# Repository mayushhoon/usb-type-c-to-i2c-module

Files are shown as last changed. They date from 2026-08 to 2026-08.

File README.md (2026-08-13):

# USB Type-C to I2C Bridge Module using FT201X IC

## Overview
A highly compact, production-ready USB Type-C to I2C hardware bridge. This module is designed to interface high-speed USB data from a host PC directly with external I2C peripherals, displays, and sensors. 

Engineered with a strict focus on Design for Manufacturability (DFM) and Design for Assembly (DFA), the board packs power regulation, signal filtering, and data conversion into a 31x17mm footprint using high-density 0603 surface-mount components.

| Front Side | Back Side |
| :---: | :---: |
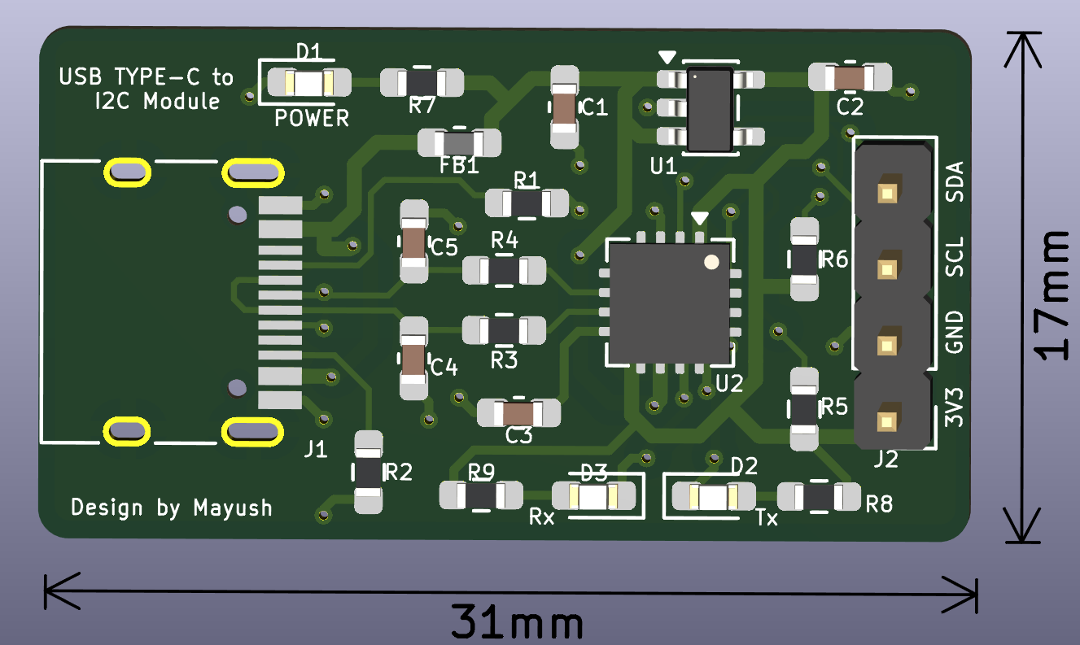
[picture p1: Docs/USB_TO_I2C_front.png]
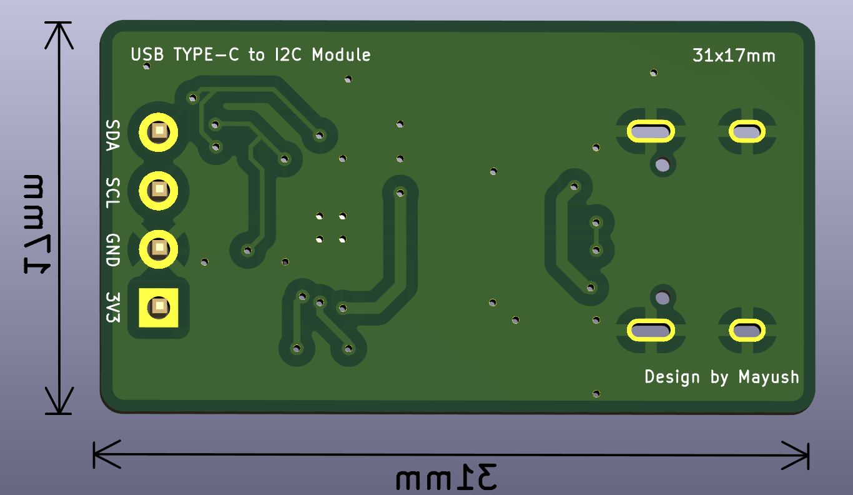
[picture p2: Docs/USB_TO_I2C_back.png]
|  |  |

## Hardware Architecture
* **Core Bridge IC:** FTDI FT201X (Full-Speed USB to I2C Bridge).
* **Power Regulation:** Integrated 3.3V Low Dropout (LDO) regulator to provide clean, low-noise power to both the internal logic and external I2C header.
* **EMI Suppression:** Custom RC low-pass filter network (27Ω / 47pF) on the USB D+ and D- data lines for impedance matching and high-frequency noise mitigation.
* **Bus Stability:** Dedicated 2.2kΩ hardware pull-up resistors on the SDA and SCL lines to guarantee sharp signal edge-rates at Fast Mode (400 kHz) clock speeds.
* **Host Isolation:** Ferrite bead input filtering on the 5V VBUS to block high-frequency switching noise from the host PC.

## Diagnostic Interface
The module features a custom diagnostic LED array utilizing the configurable CBUS pins of the FT201X to provide immediate visual feedback of bus states:
* 🔴 **RED:** Power indicator (Tapped downstream of the input filter).
* 🔵 **BLUE:** RX Data Activity.
* 🟢 **GREEN:** TX Data Activity.

## Board Specifications
| Feature | Specification |
| :--- | :--- |
| **Dimensions** | 31mm x 17mm |
| **Layers** | 2-Layer FR4 (Solid bottom ground plane) |
| **Component Size** | 0603 Imperial (Passives & LEDs) |
| **Trace Width** | 0.254mm (10 mil) standard |
| **Input Interface** | USB Type-C (Receptacle) |
| **Output Interface** | 4-Pin 2.54mm Header (3V3, GND, SCL, SDA) |

## Repository Structure
* `/Hardware` - Source KiCad 7/8 project files (Schematic and PCB layout).
* `/Fabrication` - Manufacturing package (Gerbers, Excellon Drill files, and CSV BOM).
* `/Docs` - PDF schematics, 3D renders, and component datasheets.

## Assembly Notes
This board was intentionally designed to be hand-solderable despite its small size. All passive components use the `_HandSoldering` 0603 footprint variants to provide extended pad surface area for tweezer and iron assembly. Ensure the FT201X internal CBUS pins are configured via the FT_Prog utility to activate the TX and RX LED indicators after assembly.

## Author
**Designed by MAYUSH RAHANGDALE**

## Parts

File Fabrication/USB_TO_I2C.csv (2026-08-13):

Reference | Qty | Value | DNP | Exclude from BOM | Exclude from Board | Footprint | Datasheet
C1,C2 | 2 | 1u |  |  |  | Capacitor_SMD:C_0603_1608Metric_Pad1.08x0.95mm_HandSolder | ~
C3 | 1 | 100n |  |  |  | Capacitor_SMD:C_0603_1608Metric_Pad1.08x0.95mm_HandSolder | ~
C4,C5 | 2 | 47p |  |  |  | Capacitor_SMD:C_0603_1608Metric_Pad1.08x0.95mm_HandSolder | ~
D1 | 1 | RED |  |  |  | LED_SMD:LED_0603_1608Metric_Pad1.05x0.95mm_HandSolder | ~
D2 | 1 | GREEN |  |  |  | LED_SMD:LED_0603_1608Metric_Pad1.05x0.95mm_HandSolder | ~
D3 | 1 | BLUE |  |  |  | LED_SMD:LED_0603_1608Metric_Pad1.05x0.95mm_HandSolder | ~
FB1 | 1 | FerriteBead |  |  |  | Inductor_SMD:L_0603_1608Metric_Pad1.05x0.95mm_HandSolder | ~
J1 | 1 | USB_C_Receptacle_USB2.0_16P |  |  |  | Connector_USB:USB_C_Receptacle_HRO_TYPE-C-31-M-12 | https://www.usb.org/sites/default/files/documents/usb_type-c.zip
J2 | 1 | Conn_01x04_Pin |  |  |  | Connector_PinHeader_2.54mm:PinHeader_1x04_P2.54mm_Vertical | ~
R1,R2 | 2 | 5.1k |  |  |  | Resistor_SMD:R_0603_1608Metric_Pad0.98x0.95mm_HandSolder | ~
R3,R4 | 2 | 27 |  |  |  | Resistor_SMD:R_0603_1608Metric_Pad0.98x0.95mm_HandSolder | ~
R5,R6 | 2 | 2.2k |  |  |  | Resistor_SMD:R_0603_1608Metric_Pad0.98x0.95mm_HandSolder | ~
R7 | 1 | 1k |  |  |  | Resistor_SMD:R_0603_1608Metric_Pad0.98x0.95mm_HandSolder | ~
R8,R9 | 2 | 330 |  |  |  | Resistor_SMD:R_0603_1608Metric_Pad0.98x0.95mm_HandSolder | ~
U1 | 1 | TLV70233_SOT23-5 |  |  |  | Package_TO_SOT_SMD:SOT-23-5 | http://www.ti.com/lit/ds/symlink/tlv702.pdf
U2 | 1 | FT201XQ |  |  |  | Package_DFN_QFN:QFN-16-1EP_4x4mm_P0.65mm_EP2.1x2.1mm | https://www.ftdichip.com/Support/Documents/DataSheets/ICs/DS_FT201X.pdf

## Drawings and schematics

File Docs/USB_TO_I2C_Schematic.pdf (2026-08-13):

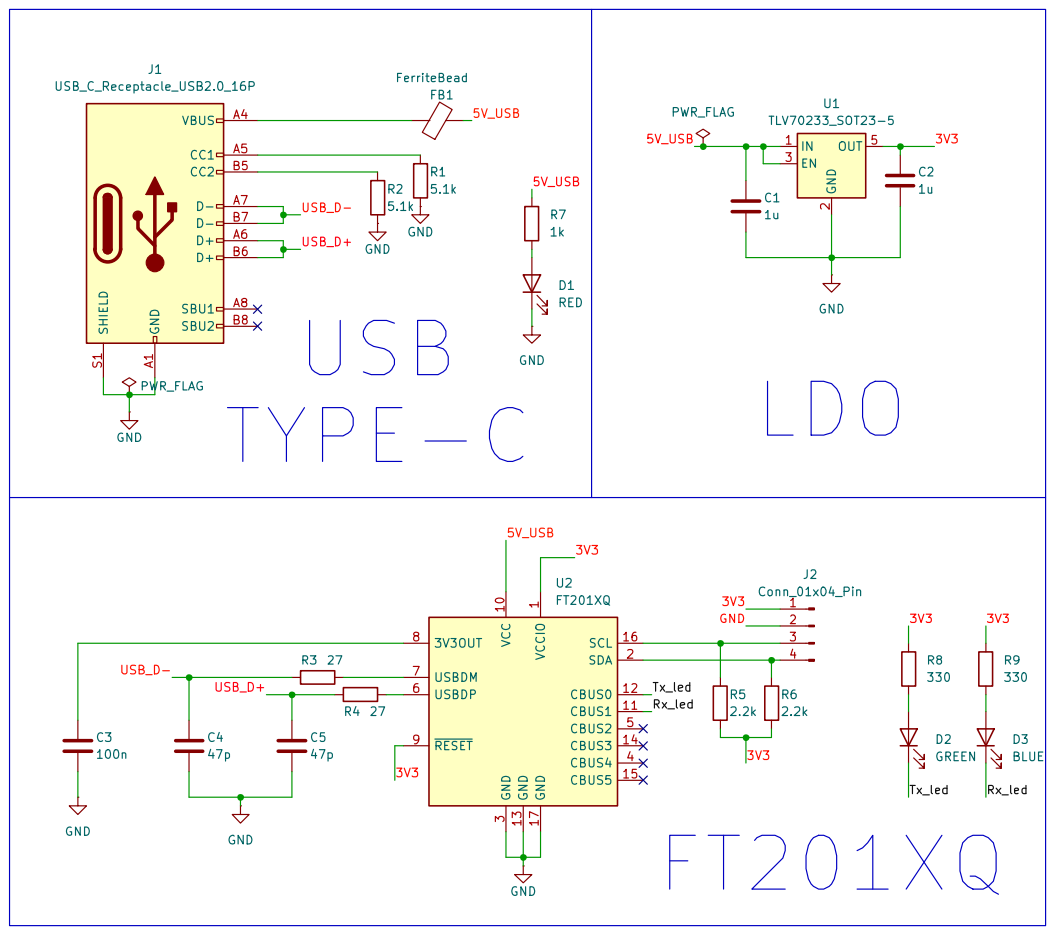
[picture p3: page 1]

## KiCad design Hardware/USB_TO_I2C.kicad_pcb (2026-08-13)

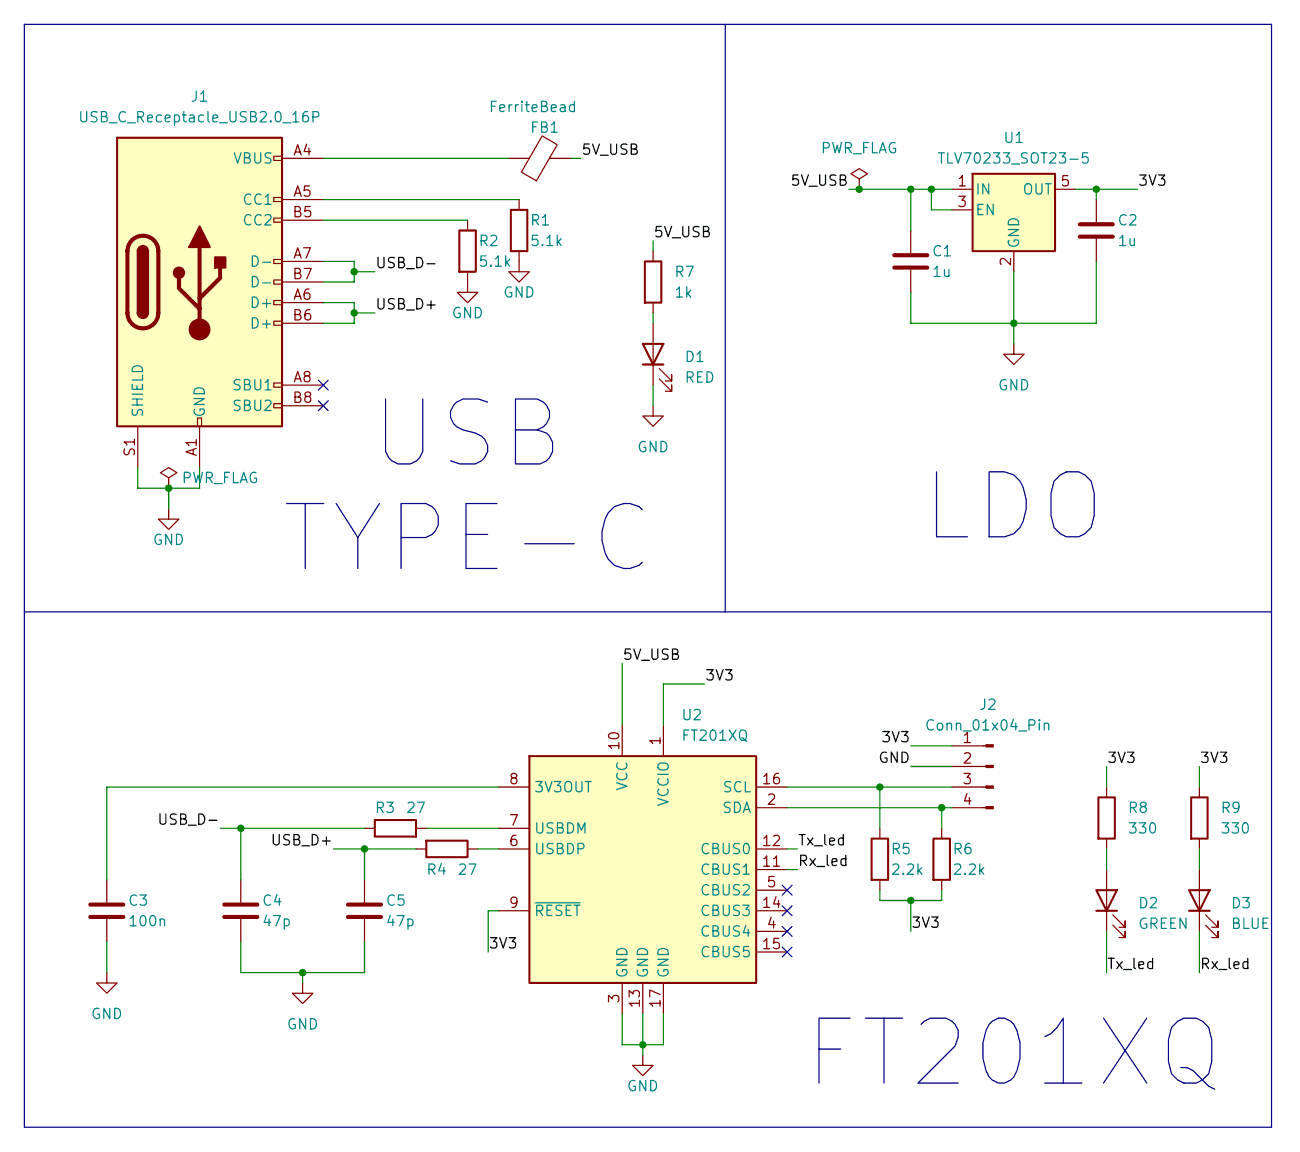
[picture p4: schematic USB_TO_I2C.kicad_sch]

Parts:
C1, C2: 1u; C_0603_1608Metric_Pad1.08x0.95mm_HandSolder
C3: 100n; C_0603_1608Metric_Pad1.08x0.95mm_HandSolder
C4, C5: 47p; C_0603_1608Metric_Pad1.08x0.95mm_HandSolder
D1: RED; LED_0603_1608Metric_Pad1.05x0.95mm_HandSolder
D2: GREEN; LED_0603_1608Metric_Pad1.05x0.95mm_HandSolder
D3: BLUE; LED_0603_1608Metric_Pad1.05x0.95mm_HandSolder
FB1: FerriteBead; L_0603_1608Metric_Pad1.05x0.95mm_HandSolder
J1: USB_C_Receptacle_USB2.0_16P; USB_C_Receptacle_HRO_TYPE-C-31-M-12
J2: Conn_01x04_Pin; PinHeader_1x04_P2.54mm_Vertical
R1, R2: 5.1k; R_0603_1608Metric_Pad0.98x0.95mm_HandSolder
R3, R4: 27; R_0603_1608Metric_Pad0.98x0.95mm_HandSolder
R5, R6: 2.2k; R_0603_1608Metric_Pad0.98x0.95mm_HandSolder
R7: 1k; R_0603_1608Metric_Pad0.98x0.95mm_HandSolder
R8, R9: 330; R_0603_1608Metric_Pad0.98x0.95mm_HandSolder
U1: TLV70233_SOT23-5; SOT-23-5
U2: FT201XQ; QFN-16-1EP_4x4mm_P0.65mm_EP2.1x2.1mm

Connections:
/3V3: C2.1, J2.1, R5.2, R6.2, R8.1, R9.1, U1.5 (OUT), U2.1 (VCCIO), U2.9 (~RESET)
/5V_USB: C1.1, FB1.2, R7.1, U1.1 (IN), U1.3 (EN), U2.10 (VCC)
/Rx_led: D3.1 (K), U2.11 (CBUS1)
/Tx_led: D2.1 (K), U2.12 (CBUS0)
/USB_D+: C5.1, J1.A6 (D+), J1.B6 (D+), R4.2
/USB_D-: C4.1, J1.A7 (D-), J1.B7 (D-), R3.1
GND: C1.2, C2.2, C3.2, C4.2, C5.2, D1.1 (K), J1.A1 (GND), J1.A12 (GND), J1.B1 (GND), J1.B12 (GND), J1.S1 (SHIELD), J2.2, R1.2, R2.2, U1.2 (GND), U2.3 (GND), U2.13 (GND), U2.17 (GND)
unnamed: D1.2 (A), R7.2
unnamed: D2.2 (A), R8.2
unnamed: D3.2 (A), R9.2
unnamed: FB1.1, J1.A4 (VBUS), J1.A9 (VBUS), J1.B4 (VBUS), J1.B9 (VBUS)
unnamed: J1.A5 (CC1), R1.1
unnamed: J1.B5 (CC2), R2.1
unnamed: J2.3, R5.1, U2.16 (SCL)
unnamed: J2.4, R6.1, U2.2 (SDA)
unnamed: C3.1, U2.8 (3V3OUT)
unnamed: R3.2, U2.7 (USBDM)
unnamed: R4.1, U2.6 (USBDP)

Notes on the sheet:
FT201XQ
USB TYPE-C
LDO

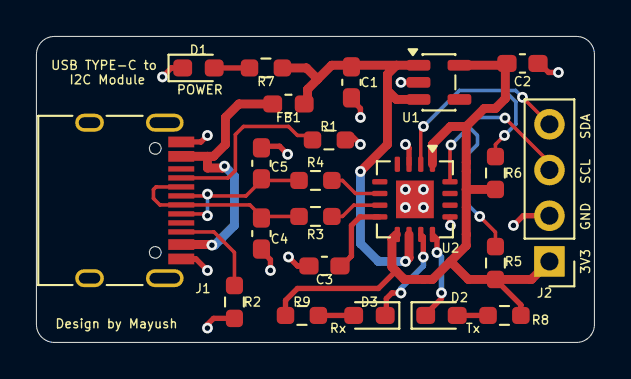
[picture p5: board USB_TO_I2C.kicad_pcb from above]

Board: 2 copper layers, 31.0 x 17.0 mm, 22 parts (0 on the bottom side), 18 nets.
